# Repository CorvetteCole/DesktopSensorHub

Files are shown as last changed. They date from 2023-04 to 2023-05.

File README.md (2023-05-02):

# DesktopSensorHub
A board designed to connect to a desktop computer via USB, and add sensors such as ambient light, color, proximity, gestures, and more via standard Linux IIO

## Preview (from OSHPark)
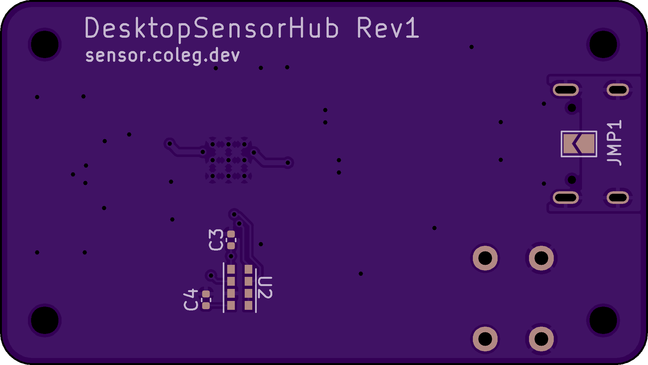
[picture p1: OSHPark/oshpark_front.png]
Front of board

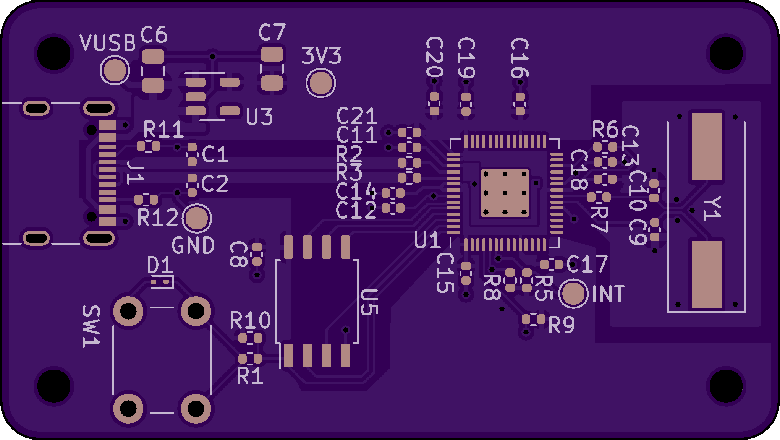
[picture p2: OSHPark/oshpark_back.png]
Back of board


## Software references
- Article about the below: https://hackaday.com/2022/10/31/need-an-usb-i2c-adapter-use-your-pico/
- Repo for RP2040 i2c interface: https://github.com/Nicolai-Electronics/rp2040-i2c-interface
- Linux module compilation/setup: https://petermolnar.net/article/linux-i2c-iio-collectd/

## Board references
- Adafruit breakout for Avago APDS9960 proxmity, ALS, color, gesture sensor: https://www.adafruit.com/product/3595
- Adafruit QT2040 board for i2c -> USB: https://www.adafruit.com/product/5056

## Roadmap
- [x] Test prototype once boards arrive
  - Problem encountered, APDS9960 iio i2c driver needs an interrupt, but no interrupt is provided via RP2040 i2c bridge. Need to figure out if we can somehow provide an interrupt over USB or maybe by acting as a GPIO expander as well
- [x] Design PCB, preferrably with USB-C connector on sensor hub
- [ ] Design 3D printed case for sensor so it can mount on top of your PC like a webcam (maybe?)
- [x] Test v1 PCB
  - With much pain, eventually 1 working board as a result, lessons learned
- [ ] Optimize, reduce footprint
  - Remove button, switch to small header, move RP2040 & flash closer to USB port
  - Remove capacitors from USB data lines (not needed)
  - Add test points for APDS9960
  - Move APDS9960 to front of board for ease of assembly
  - Switch to crystal with smaller footprint (less tall)
  - Change test points to plates through holes(?)
  - Break out some extra GPIO because why not
- [ ] Test v2 PCB
- [ ] Release, make repo public (probably no one will care)
- [ ] Write userspace daemon to handle gestures, color temperature calculation and display color adjustment. Would handle display brightness adjustment too, but I think that would be better served by [wluma](https://github.com/maximbaz/wluma)
- [ ] Figure out if wake on proximity sensor is possible

## Related projects
- ColorhugALS: https://blogs.gnome.org/hughsie/2015/05/27/colorhugals-and-sensor-hid/ by https://hughsie.com/. Maybe send him an email once you have something interesting?

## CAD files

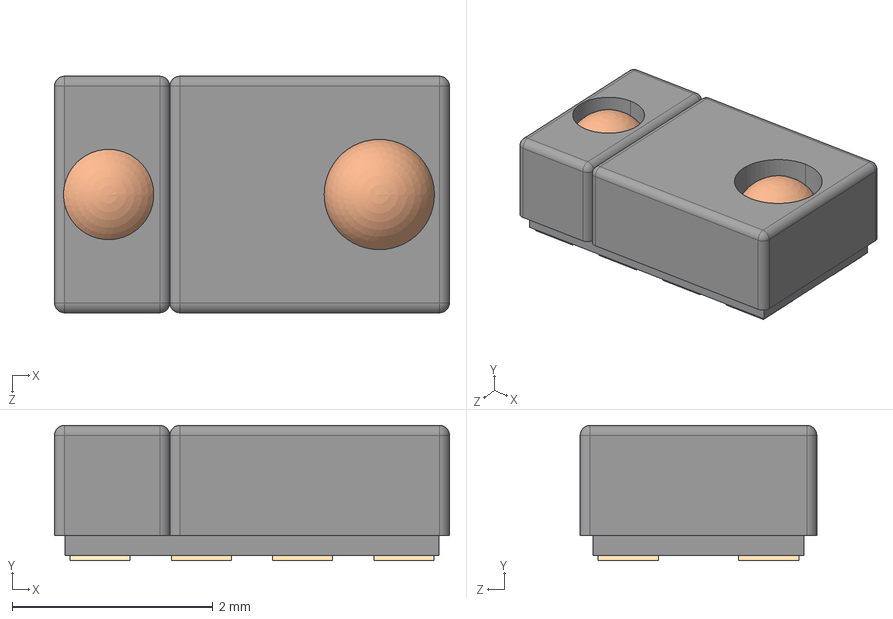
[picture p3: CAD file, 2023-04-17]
3dmodels/APDS-9960.step
3.94 x 1.35 x 2.36 mm

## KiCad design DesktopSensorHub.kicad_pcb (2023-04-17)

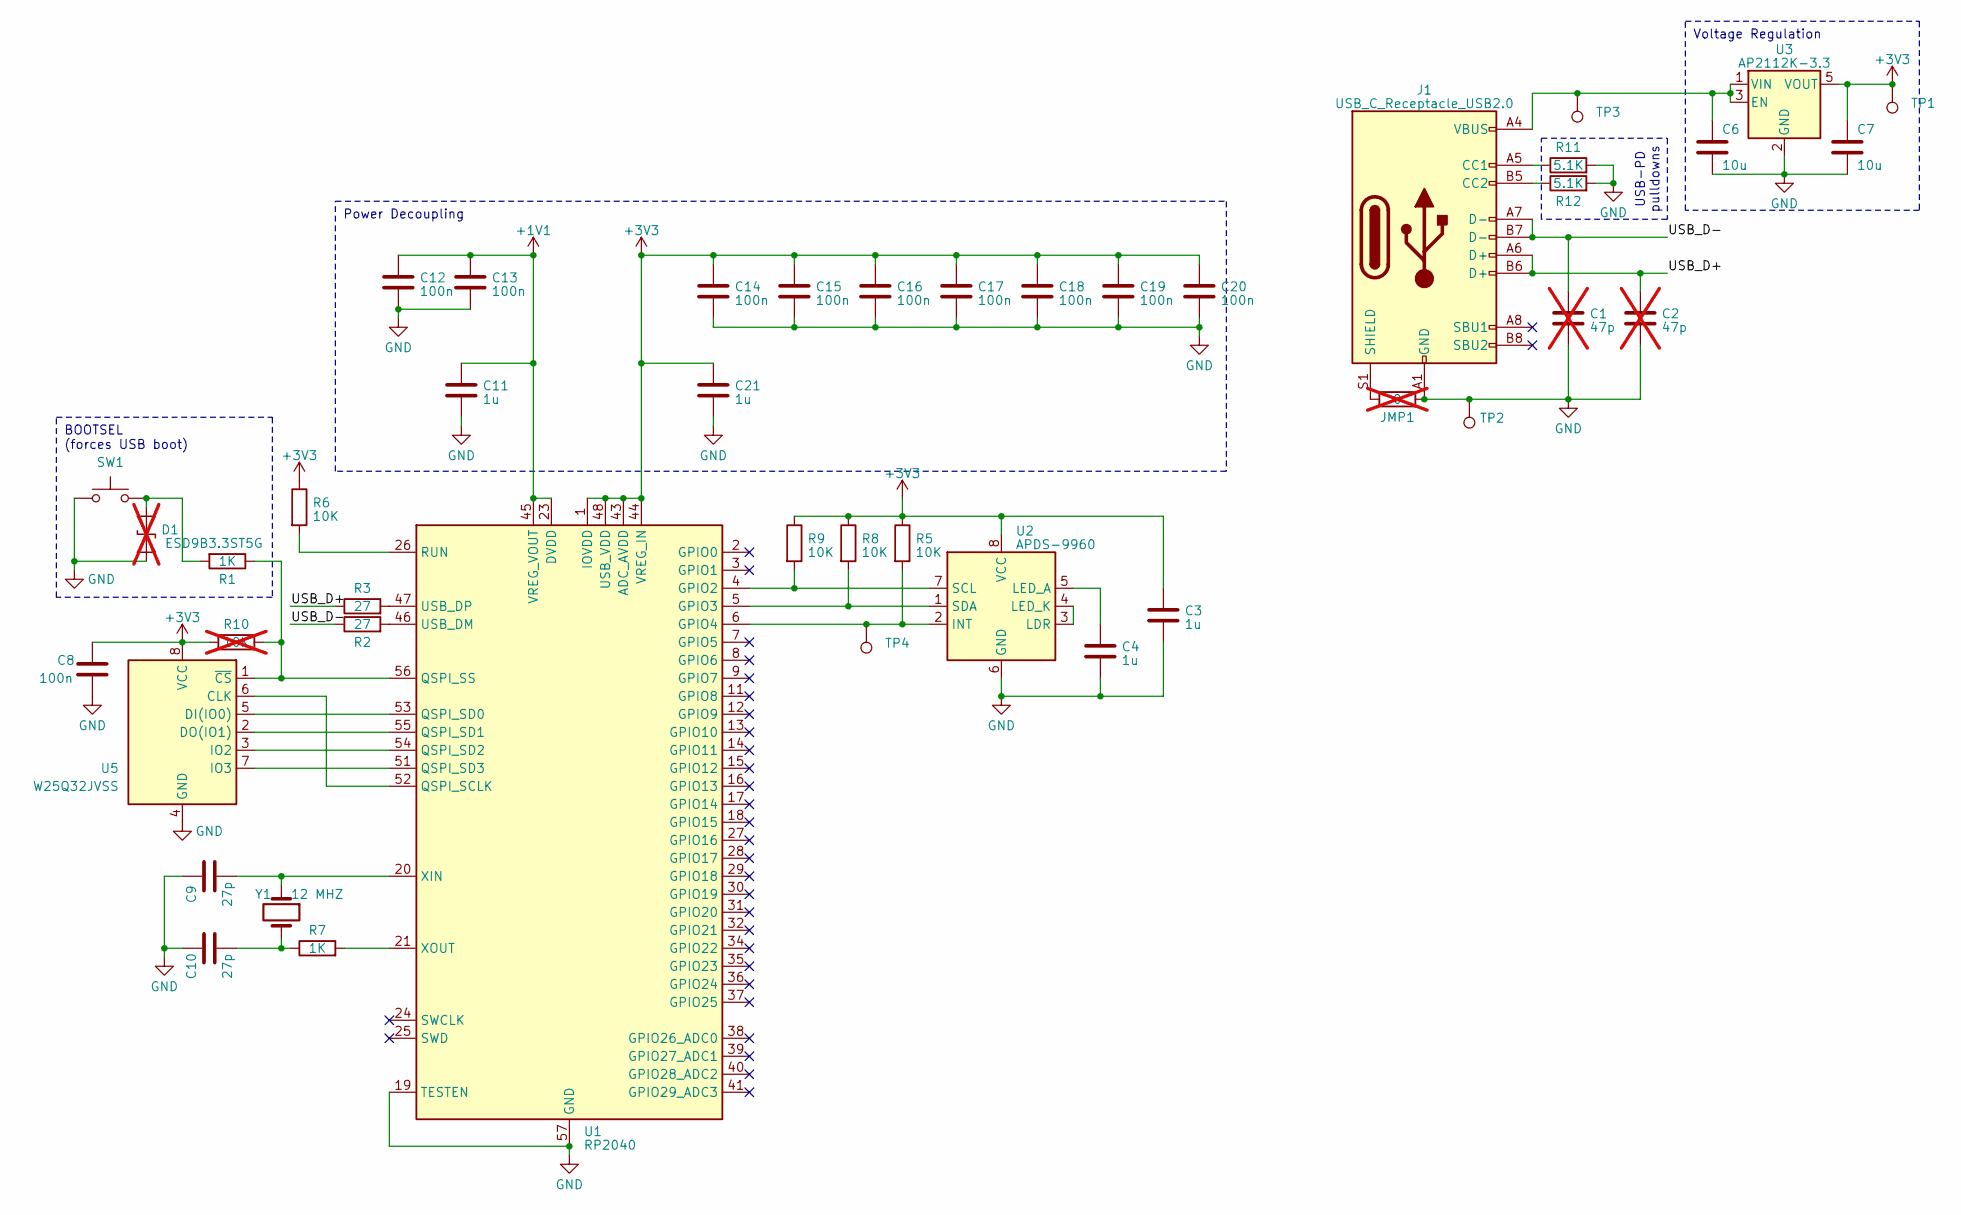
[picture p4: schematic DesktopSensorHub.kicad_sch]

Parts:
C1, C2: 47p; C_0402_1005Metric; not fitted
C3, C4, C11, C21: 1u; C_0402_1005Metric
C6, C7: 10u; C_0805_2012Metric
C8, C12, C13, C14, C15, C16, C17, C18, C19, C20: 100n; C_0402_1005Metric
C9, C10: 27p; C_0402_1005Metric
D1: ESD9B3.3ST5G; D_SOD-923; not fitted
J1: USB_C_Receptacle_USB2.0; USB_C_Receptacle_GCT_USB4105-xx-A_16P_TopMnt_Horizontal; MPN USB4105-GF-A
JMP1: 0; SolderJumper-2_P1.3mm_Open_TrianglePad1.0x1.5mm; not fitted
R1: 1K; R_0402_1005Metric; Tolerance 1%
R2, R3: 27; R_0402_1005Metric; Tolerance 1%
R5, R6, R8, R9: 10K; R_0402_1005Metric
R7: 1K; R_0402_1005Metric
R10: 10K; R_0402_1005Metric; not fitted
R11, R12: 5.1K; R_0402_1005Metric
SW1: TS02-66-50-BK-160-LCR-D; SW_PUSH_6mm_H5mm
TP1, TP2, TP3, TP4: TestPoint; TestPoint_Pad_D1.5mm
U1: RP2040; RP2040-QFN-56
U2: APDS-9960; Avago_APDS-9960
U3: AP2112K-3.3; SOT-23-5
U5: W25Q32JVSS; SOIC-8_5.275x5.275mm_P1.27mm
Y1: 12 MHZ; Crystal_SMD_HC49-SD; MPN ABLS-12.000MHZ-B4-T

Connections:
+1V1: C11.1, C12.1, C13.1, U1.23 (DVDD), U1.45 (VREG_VOUT), U1.50 (DVDD)
+3V3: C3.1, C7.1, C8.1, C14.1, C15.1, C16.1, C17.1, C18.1, C19.1, C20.1, C21.1, R5.1, R6.1, R8.1, R9.1, R10.1, TP1.1, U1.1 (IOVDD), U1.10 (IOVDD), U1.22 (IOVDD), U1.33 (IOVDD), U1.42 (IOVDD), U1.43 (ADC_AVDD), U1.44 (VREG_IN), U1.48 (USB_VDD), U1.49 (IOVDD), U2.8 (VCC), U3.5 (VOUT), U5.8 (VCC)
/USB_D+: C2.1, J1.A6 (D+), J1.B6 (D+), R3.1
/USB_D-: C1.1, J1.A7 (D-), J1.B7 (D-), R2.1
GND: C1.2, C2.2, C3.2, C4.2, C6.2, C7.2, C8.2, C9.1, C10.1, C11.2, C12.2, C13.2, C14.2, C15.2, C16.2, C17.2, C18.2, C19.2, C20.2, C21.2, D1.2 (A2), J1.A1 (GND), J1.A12 (GND), J1.B1 (GND), J1.B12 (GND), JMP1.2, R11.2, R12.2, SW1.1, TP2.1, U1.19 (TESTEN), U1.57 (GND), U2.6 (GND), U3.2 (GND), U5.4 (GND)
unnamed: C10.2, R7.1, Y1.2
unnamed: D1.1 (A1), R1.2, SW1.2
unnamed: J1.A5 (CC1), R11.1
unnamed: J1.B5 (CC2), R12.1
unnamed: J1.S1 (SHIELD), JMP1.1
unnamed: R9.2, U1.4 (GPIO2), U2.7 (SCL)
unnamed: R8.2, U1.5 (GPIO3), U2.1 (SDA)
unnamed: R5.2, TP4.1, U1.6 (GPIO4), U2.2 (INT)
unnamed: U1.52 (QSPI_SCLK), U5.6 (CLK)
unnamed: U1.53 (QSPI_SD0), U5.5 (DI(IO0))
unnamed: U1.55 (QSPI_SD1), U5.2 (DO(IO1))
unnamed: U1.54 (QSPI_SD2), U5.3 (IO2)
unnamed: U1.51 (QSPI_SD3), U5.7 (IO3)
unnamed: R1.1, R10.2, U1.56 (QSPI_SS), U5.1 (~CS)
unnamed: R6.2, U1.26 (RUN)
unnamed: R2.2, U1.46 (USB_DM)
unnamed: R3.2, U1.47 (USB_DP)
unnamed: C9.2, U1.20 (XIN), Y1.1
unnamed: R7.2, U1.21 (XOUT)
unnamed: U2.3 (LDR), U2.4 (LED_K)
unnamed: C4.1, U2.5 (LED_A)
unnamed: C6.1, J1.A4 (VBUS), J1.A9 (VBUS), J1.B4 (VBUS), J1.B9 (VBUS), TP3.1, U3.1 (VIN), U3.3 (EN)

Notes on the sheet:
BOOTSEL (forces USB boot)
Voltage Regulation
USB-PD pulldowns
Power Decoupling

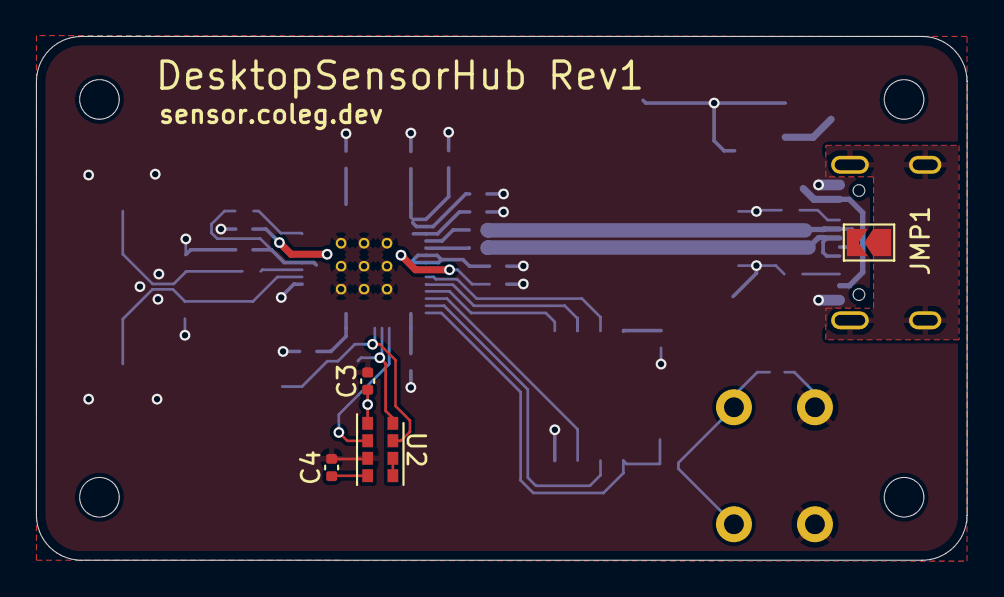
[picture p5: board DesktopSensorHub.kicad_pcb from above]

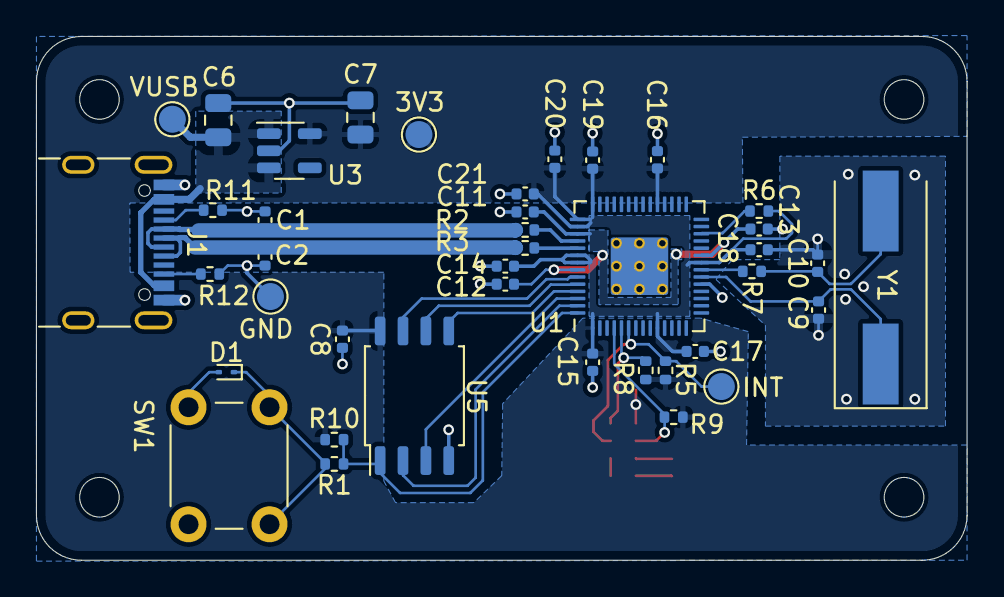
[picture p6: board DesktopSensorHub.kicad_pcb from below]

Board: 2 copper layers, 51.7 x 29.1 mm, 44 parts (40 on the bottom side), 27 nets.

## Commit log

2023-03-22 unfinished schematic, but close
    [DesktopSensorHub.kicad_pcb, DesktopSensorHub.kicad_sch]
2023-03-22 rev1 schematic finished
    [DesktopSensorHub.kicad_sch]
2023-04-04 mark additional components as do not populate
    [DesktopSensorHub.kicad_sch]
2023-04-04 remove 100uF capacitor since LED not exposed to be driven externally anyways
    [DesktopSensorHub.kicad_sch]
2023-04-04 add missing footprint for 1uF capacitors
    [DesktopSensorHub.kicad_sch]
2023-04-08 final minor tweaks to BOM
    [DesktopSensorHub.kicad_sch]
2023-04-11 varius small changes to approach a layout
    [DesktopSensorHub.kicad_pcb, DesktopSensorHub.kicad_sch]
2023-04-17 finish layout, include design files sent to OSHPark
    [APDS-9960.step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]

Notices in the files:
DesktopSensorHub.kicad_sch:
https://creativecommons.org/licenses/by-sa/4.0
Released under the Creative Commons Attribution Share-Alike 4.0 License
